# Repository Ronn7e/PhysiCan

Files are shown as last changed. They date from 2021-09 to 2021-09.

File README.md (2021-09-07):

# PhysiCan
PhysiCan es mi proyecto de Tesis para graduame en Ingeniería Electrónica. Se trata de una ortesis veterinaria robótica para la rehabilitación de rodilla en caninos. Se controla desde el celular mediante una aplicación y también monitorea (visualización de un Electromiagrama en la aplicación) la actividad muscular durante los ejercicios de rehabilitación.

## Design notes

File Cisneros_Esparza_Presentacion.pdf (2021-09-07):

### “DISEÑO E IMPLEMENTACIÓN DE UNA ORTESIS VETERINARIA DE UN GRADO DE LIBERTAD UTILIZADA EN LA FASE II DE LA REHABILITACIÓN DE RODILLA EN CANINOS DE LA FUNDACIÓN PAE”

Autores:
Cisneros Jumbo, Diego Sebastián Esparza Echanique, Ronnie Alexis

Director:
Ing. Erazo Sosa, Andres Sebastian

Fecha:
05/07/2019

## INGENIERÍA EN ELECTRÓNICA, AUTOMATIZACIÓN Y CONTROL

# CONTENIDO

▹ INTRODUCCIÓN
- Antecedentes
- Justificación e Importancia
- Alcance
- Objetivos
▹ FUNDAMENTOS TEÓRICOS
▹ READECUACIÓN DE LA ORTESIS VETERINARIA
- Parámetros de la ortesis veterinaria
- Cálculo del torque para mover la pierna del canino
- Selección del actuador
- Adaptación física de la ortesis
- Parámetros para realizar los ejercicios de rehabilitación
- Sistema de control

2

▹ CIRCUITO PARA
ELECTROMIOGRAFÍA EN CANINOS
- Parámetros de un
electromiograma (EMG)
- Diseño del circuito
- Análisis para el uso del EMG en caninos
▹ DISEÑO DE LA APLICACIÓN MÓVIL ▹ RESULTADOS
- Integración de la ortesis + EMG + App (Sistema PhysiCan)
- Funcionamiento
▹ CONCLUSIONES

1.

# INTRODUCCIÓN

### La fisioterapia veterinaria a través de los años…

3

4

# INTRODUCCIÓN

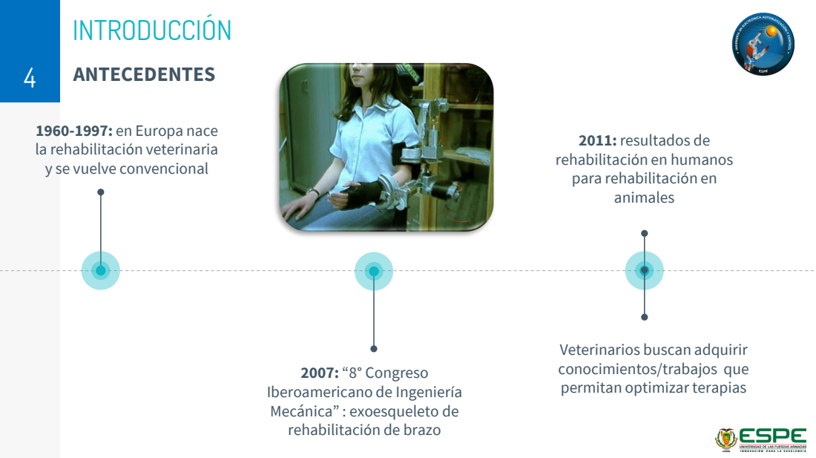
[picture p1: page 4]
ANTECEDENTES

1960-1997: en Europa nace
la rehabilitación veterinaria
y se vuelve convencional

2011: resultados de
rehabilitación en humanos
para rehabilitación en
animales

Veterinarios buscan adquirir
conocimientos/trabajos que
permitan optimizar terapias

2007: “8° Congreso
Iberoamericano de Ingeniería
Mecánica” : exoesqueleto de
rehabilitación de brazo

5

# INTRODUCCIÓN

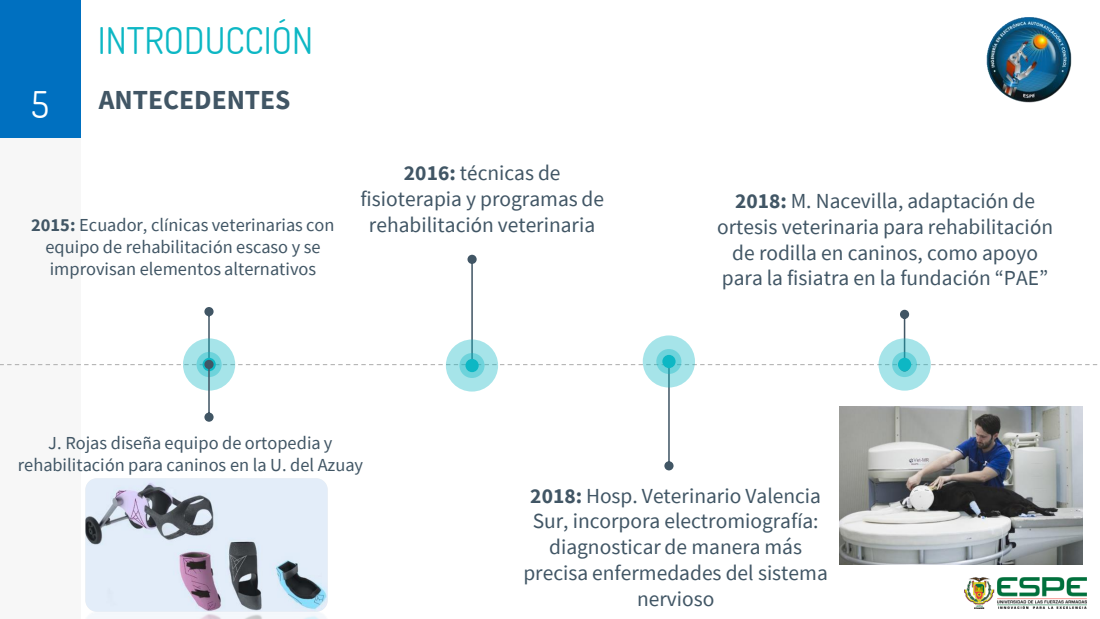
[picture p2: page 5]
ANTECEDENTES; nervioso

2016: técnicas de
fisioterapia y programas de
rehabilitación veterinaria

2018: M. Nacevilla, adaptación de
ortesis veterinaria para rehabilitación
de rodilla en caninos, como apoyo
para la fisiatra en la fundación “PAE”

2015: Ecuador, clínicas veterinarias con
equipo de rehabilitación escaso y se
improvisan elementos alternativos

J. Rojas diseña equipo de ortopedia y
rehabilitación para caninos en la U. del Azuay

2018: Hosp. Veterinario Valencia
Sur, incorpora electromiografía:
diagnosticar de manera más
precisa enfermedades del sistema

# INTRODUCCIÓN

JUSTIFICACIÓN E IMPORTANCIA
☐ En el país no ha existido avance en cuanto a ortopedia canina a nivel tecnológico.

☐ PAE, clínica que posee la Ortesis de Rehabilitación creada por Ing. Mireya Nacevilla con puntos a mejorar.

☐ 2013, REDVET: “La terapia física en medicina veterinaria es un tema nuevo que se debe integrar como parte de los tratamientos en las clínicas… con uso de nueva tecnología”.

6

# INTRODUCCIÓN

JUSTIFICACIÓN E IMPORTANCIA
☐ Para 2016 las mascotas han pasado de ser animales para cuidado y seguridad a considerarse como parte de la familia y solo en Quito están presentes en el 43% de los hogares. Teniendo un mercado nacional de 58 millones de dólares.

☐ Plan Nacional para el Buen Vivir (2017-2021): Objetivo 5, Política 5.3 : Promover la investigación, formación, capacidad y transferencia tecnológica, innovación y emprendimiento, en articulación con las necesidades sociales, para impulsar el cambio en la matriz productiva.

☐ Reglamento Nacional de Tenencia de Perros: Art 3: es obligación del propietario otorgar las condiciones de vida adecuadas y un hábitat dentro de un entorno saludable. (Secretaría General, Ministerio de Salud, 2009)

6

# INTRODUCCIÓN

ALCANCE

☐ Automatización de los ejercicios de rehabilitación, de manera que la fisiatra pueda atender otros pacientes a la par.
☐ Trabajar sobre el prototipo de M. Nacevilla: nuevo motor, sensado de actividad muscular (EMG), aumentar prestaciones aplicación móvil.
☐ Aumentar rangos de movimiento (limitado de 120° y 80° ), capacidad de carga del motor, control de velocidad, generación de historia clínica.

8

# INTRODUCCIÓN

8

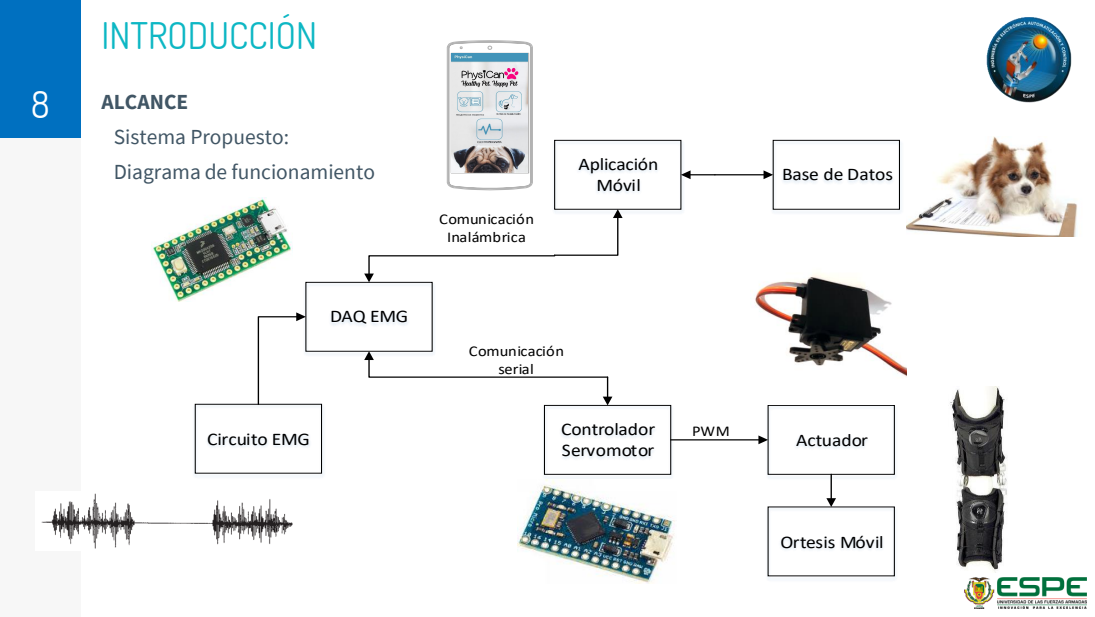
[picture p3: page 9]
Circuito EMG; Aplicación Móvil; Controlador; Servomotor; Actuador; Ortesis Móvil; DAQ EMG; Comunicación Inalámbrica; Comunicación serial; PWM

ALCANCE
Sistema Propuesto:
Diagrama de funcionamiento

Base de Datos

# INTRODUCCIÓN

OBJETIVO GENERAL

## ☐ Diseñar e implementar un prototipo portátil de ortesis de un grado de libertad utilizada en la rehabilitación de rodilla en caninos con

visualización EMG digital.

10

# INTRODUCCIÓN

OBJETIVOS ESPECÍFICOS
☐ Implementar un controlador y actuador adecuados

☐ Nueva interfaz gráfica

☐ Nuevo método de control

☐ Monitoreo EMG

☐ Manejo correcto del actuador

☐ Protocolo de transmisión de datos

11

2.

# FUNDAMENTOS TEÓRICOS

12

# FUNDAMENTOS TEÓRICOS

CINESITERAPIA PASIVA
“…Conjunto de técnicas de dos tipos, manuales o instrumentales que buscan el movimiento de segmentos corporales mediante un elemento que aplica una fuerza externa…” (Mejía & Saavedra, 2008).

ORTESIS VETERINARIA
“… Dispositivo ortopédico aplicado de forma externa en el cuerpo o extremidad…” (Rubio Fernández, 2011)

RANGOS DE MOVIMIENTO PASIVO (PROM)
“… Los rangos o gama de movimientos pasivos comprenden el grado de movilidad que se lograría en determinada articulación después de aplicar una fuerza externa…” (Ruiz & Amils, 2011)

12

# FUNDAMENTOS TEÓRICOS

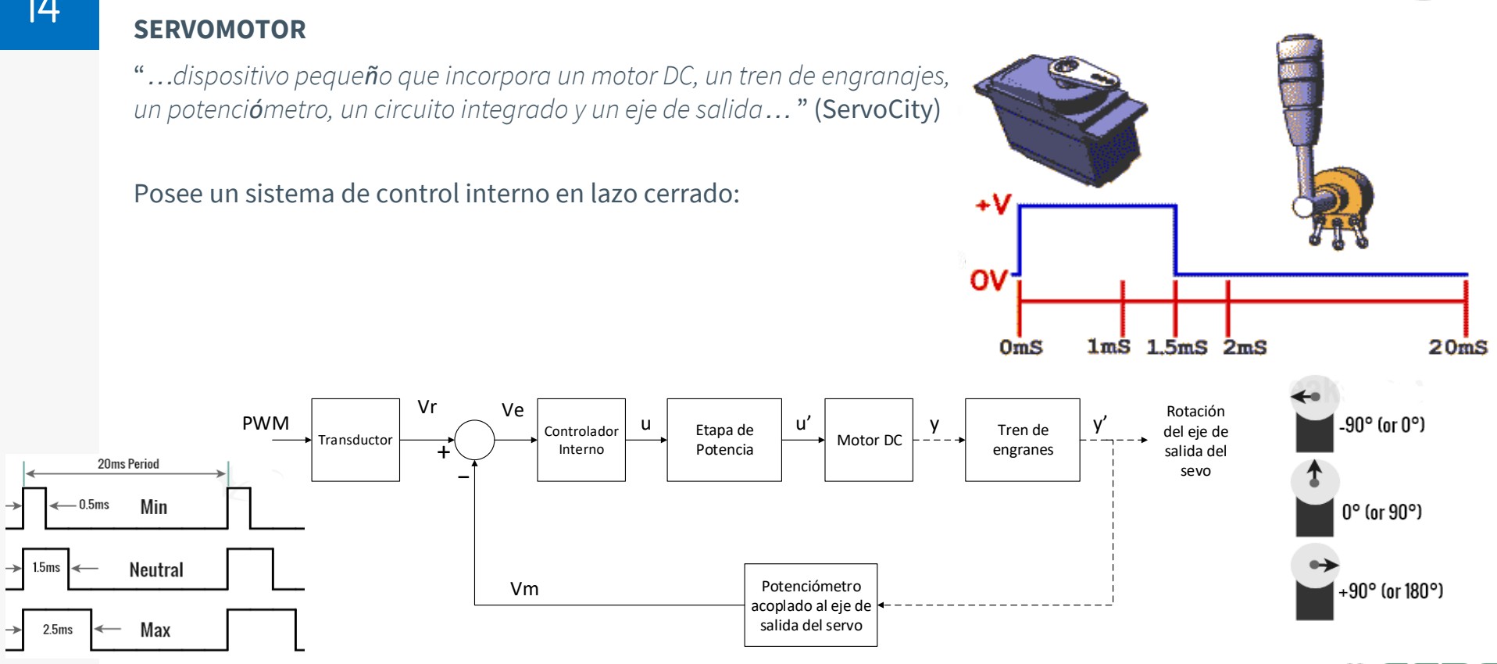
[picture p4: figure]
SERVOMOTOR; Transductor; Controlador; Interno; Etapa de Potencia; Potenciómetro acoplado al eje de salida del servo; Motor DC; Tren de; engranes; PWM; Rotación del eje de salida del sevo

“…dispositivo pequeño que incorpora un motor DC, un tren de engranajes, un potenciómetro, un circuito integrado y un eje de salida… ” (ServoCity)

14

Posee un sistema de control interno en lazo cerrado:

ELECTROMIOGRAFÍA
“… Es una prueba para estudiar como funcionan muchos de los nervios que transmiten la sensibilidad y la fuerza, así como los músculos…” (Agencia Valenciana de Salud)

15

# FUNDAMENTOS TEÓRICOS

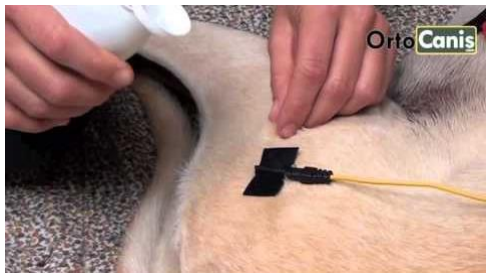
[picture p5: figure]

REGISTRO DE LA ACTIVIDAD ELECTRICA DURANTE LA CONTRACCIÓN MUSCULAR

# FUNDAMENTOS TEÓRICOS

16

☐ Estudios Clínicos, Asociación Argentina de Neurología Veterinaria

INSERCIÓN DE ELECTRODO DE AGUJA

MUSCULO ESTIMULADO/MUSCULO EN REPOSO MOVIMIENTO VOLUNTARIO

3.

# READECUACIÓN DE LA ORTESIS VETERINARIA

17

La tecnología aplicada a la rehabilitación de caninos.

# READECUACIÓN DE LA ORTESIS VETERINARIA

PARÁMETROS DE LA ORTESIS VETERINARIA

☐ Modelo Caerus CCL Stifle (Knee) Brace (XS):

18

Tamaño | Longitud de la tibia [cm] | Masa [kg]
X-Small | 8.89 – 13.97 | 4.54 – 11.34 kg
- Diseño modular
- Bisagras para ajuste/bloqueo del movimiento de la rodilla
- Sistema giratorio de fijación

# READECUACIÓN DE LA

# ORTESIS VETERINARIA

CÁLCULO DEL TORQUE PARA MOVER LA PIERNA DEL CANINO ☐ Sistema de palancas del miembro posterior:
- Tercer tipo o interpotente:
Fp: fuerza de potencia o motriz
Fr: Fuerza de carga o resistente
Bp: brazo potente (distancia entre la potencia y el punto de apoyo)
Br : Brazo resistente (distancia entre el apoyo y la carga o resistencia)
F: rodilla o punto de apoyo
- En el canino el brazo potente (Bp) corresponde al músculo poplíteo, responsable de la flexión de la rodilla.

19

# READECUACIÓN DE LA ORTESIS VETERINARIA

CÁLCULO DEL TORQUE PARA MOVER LA PIERNA DEL CANINO ☐ Distribución de masa corporal del canino.

- Se consideró el caso más extremo
- Masa total de 11.34 kg y una longitud de la tibia de 13.97 cm.

20

Total | Muslo | Pierna | Pie
11.34 kg | 1.0206 kg | 0.417312 kg | 0.291438 kg

# READECUACIÓN DE LA 21 ORTESIS VETERINARIA

CÁLCULO DEL TORQUE PARA MOVER LA PIERNA DEL CANINO

Mr = Mp

Mr = Fr1 × Br1 + Fr2 × Br2

Fr1 = 0.4173 + 0.150 | kg | × 9.8

m
s
2 | = 5.55954 [N]
Fr2 = 0.2914 | kg | × 9.8

m
s
2 | = 2.8557 | N
Mr = 5.55954 | N | × 0.06985 | m | + 2.8557 | N | × 0.1397 | m

Mr = Mp = 0.7872[N. m]

### 13.97 cm

# READECUACIÓN DE LA ORTESIS VETERINARIA

SELECCIÓN DEL ACTUADOR

22

Características | Opción 1 | Opción 2 | Opción 3
Marca | Pololu | Pololu | Hitec
Modelo | 20Dx44L (producto 3491) | 25Dx64L (producto 3217 ) | HS-755 HB
Torque | 0.77 Nm | 1.16 Nm | 1.07 Nm
Existencia en el mercado nacional | No | Si | Si
Peso | 46 gr | 101 gr | 110 gr
Voltaje de operación | 12 V | 12 V | 4.8 V
Corriente máxima | 1600 mA | 5600 mA | 1500 mA
Sensor de posición inetegrado | No (opción para acople) | Si | Si (No accesible)
Posición del eje | Horizontal | Horizontal | Vertical
Precio | $22,95 (USA) | $39,99 | $40
Rango de movimiento angular | 0-360° | 0-360° | 0-180°

# READECUACIÓN DE LA ORTESIS VETERINARIA

ADAPTACIÓN FÍSICA DE LA ORTESIS

23

Modo de

# READECUACIÓN DE LA ORTESIS VETERINARIA

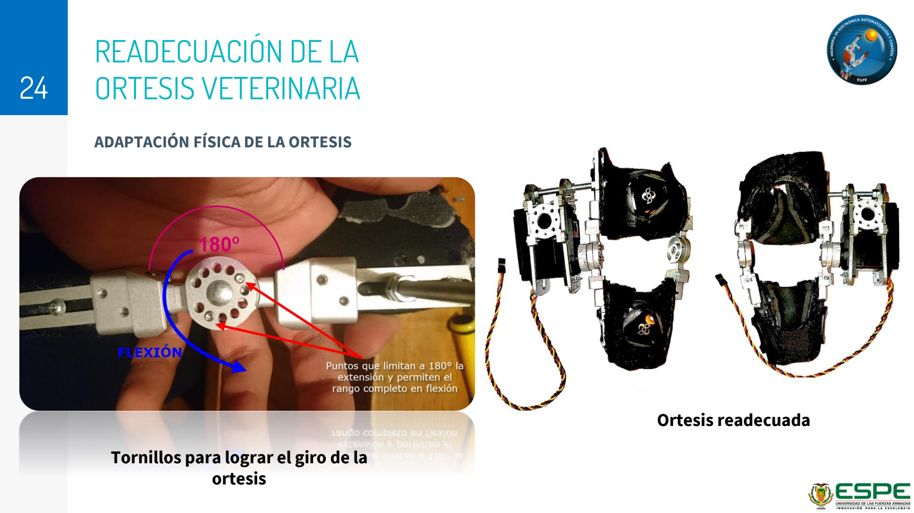
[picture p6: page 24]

ADAPTACIÓN FÍSICA DE LA ORTESIS

24

Tornillos para lograr el giro de la ortesis

Ortesis readecuada

# READECUACIÓN DE LA ORTESIS VETERINARIA

PARÁMETROS PARA REALIZAR LOS EJERCICIOS DE REHABILITACIÓN
25

# READECUACIÓN DE LA ORTESIS VETERINARIA

SISTEMA DE CONTROL

26

Parámetros de
configuración
para la
rehabilitación

Rotación
del eje de
Rotación
de la
Ortesis
Móvil

Diagrama de bloques de un sistema en lazo abierto (Kuo)

Controlador; Externo; Servomotor; Bisagra de la; Ortesis Móvil; PWM; salida del sevo

Diagrama de bloques de la ortesis readecuada

# READECUACIÓN DE LA ORTESIS VETERINARIA

SISTEMA DE CONTROL

27

Microprocesador | ATmega32U4
Alimentación / reloj | 5V
Reloj | 16 MHz
IDE de Programación | Compatible con Arduino IDE desde v1.0.1
Programación | On-Board micro-USB
Digital I/Os | 12 (5 se pueden utilizar como PWM)
Comunicación serial | Micro USB y mediante pines RX y TX
Tamaño | 1.3 x 0.7" (33.02 x 17.78 mm ) | Tarjeta de desarrollo SparkFun
Pro Micro

4.

# CIRCUITO PARA ELECTROMIOGRAFÍA EN CANINOS

28

Midiendo la atividad muscular en la rehabilitación.

# CIRCUITO PARA ELECTROMIOGRAFÍA EN CANINOS

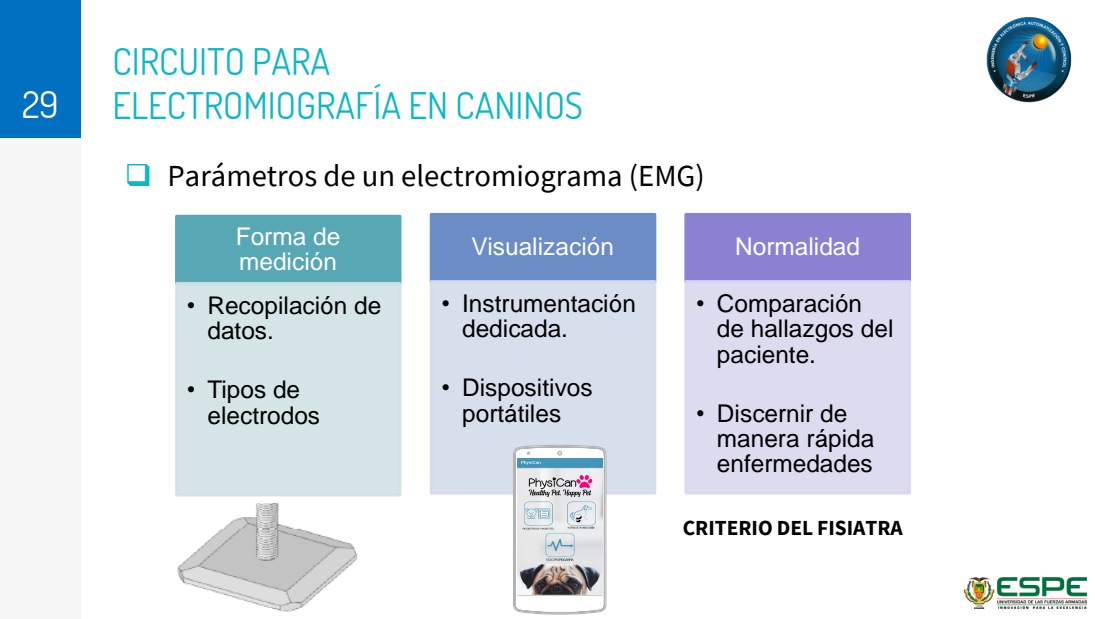
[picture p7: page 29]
Forma de medición; • Recopilación de datos.; • Tipos de electrodos; Visualización; • Instrumentación dedicada.; • Dispositivos portátiles; Normalidad; • Discernir de manera rápida enfermedades

☐ Parámetros de un electromiograma (EMG)

• Comparación
de hallazgos del
paciente.

CRITERIO DEL FISIATRA

# CIRCUITO PARA ELECTROMIOGRAFÍA EN CANINOS

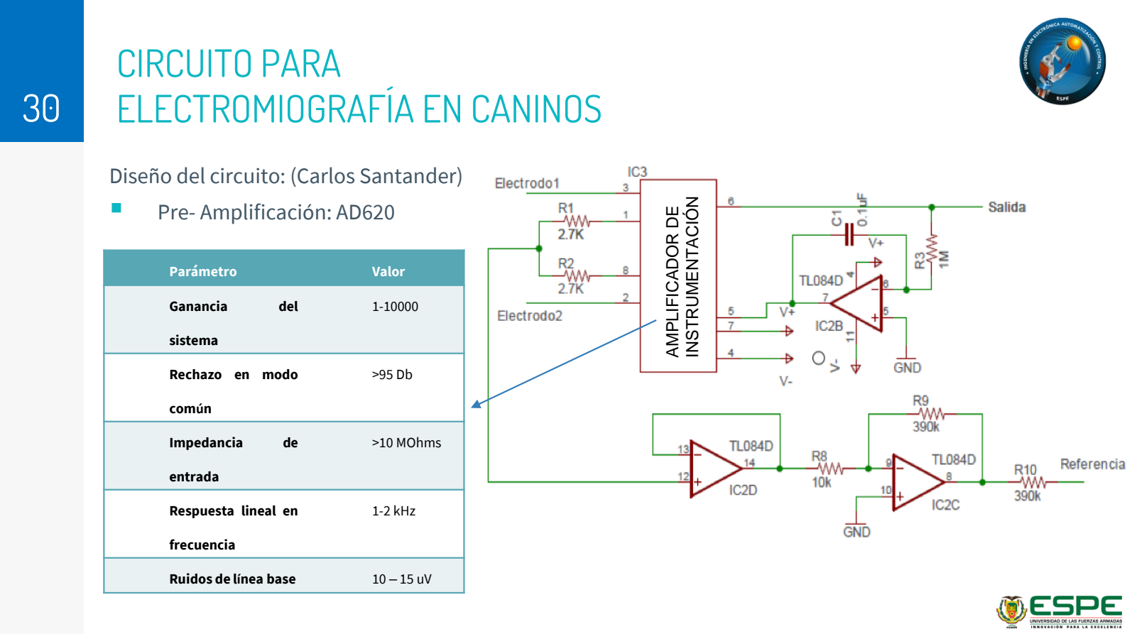
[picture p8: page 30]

Diseño del circuito: (Carlos Santander)
- Pre- Amplificación: AD620

30

Parámetro | Valor
Ganancia del sistema | 1-10000
Rechazo en modo común | >95 Db
Impedancia de entrada | >10 MOhms
Respuesta lineal en frecuencia | 1-2 kHz
Ruidos de línea base | 10 – 15 uV

AMPLIFICADOR DE

INSTRUMENTACIÓN

# CIRCUITO PARA

31 | ELECTROMIOGRAFÍA EN CANINOS | Sistema de

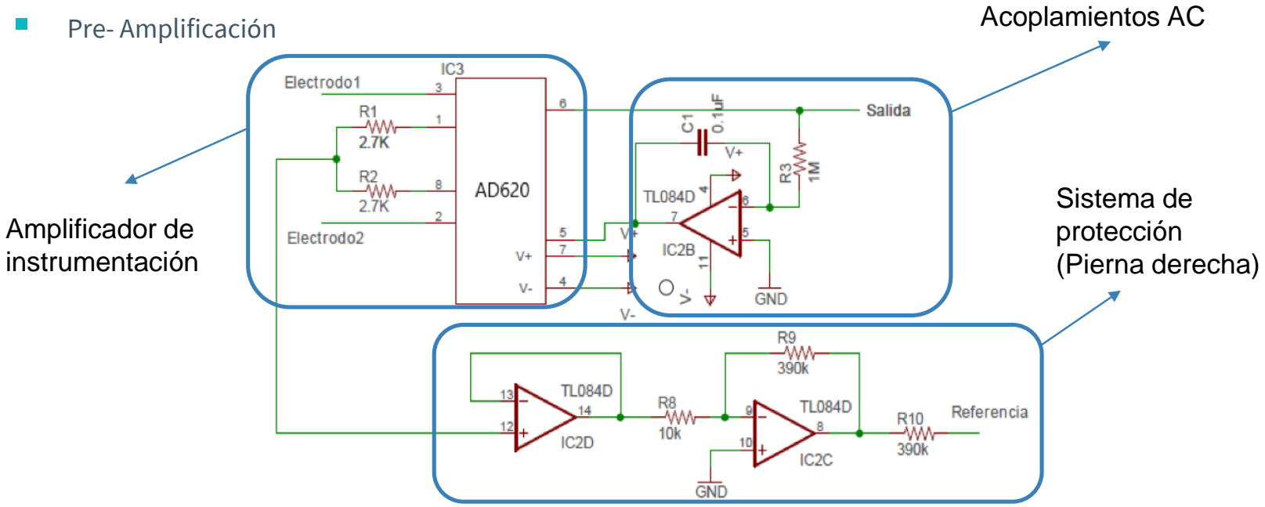
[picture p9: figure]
Acoplamientos AC; Sistema de protección (Pierna derecha); Amplificador de instrumentación; ▪ Pre- Amplificación

# CIRCUITO PARA ELECTROMIOGRAFÍA EN CANINOS

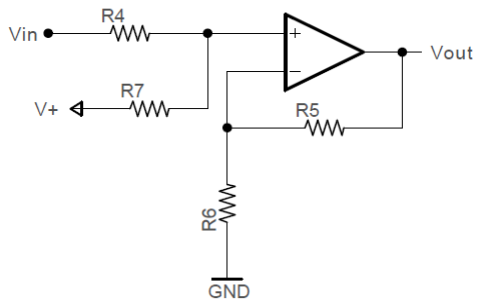
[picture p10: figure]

- Amplificación

32

Valores apropiados - A/D

Valores comerciales del
“uC” [-3;3 mV] o [-3;3 V]

Incremento
de la
amplitud

# CIRCUITO PARA ELECTROMIOGRAFÍA EN CANINOS

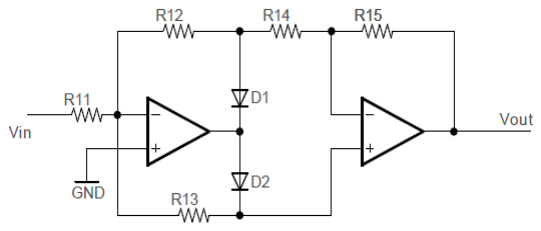
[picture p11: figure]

- Rectificación

33

Trabajo con:
Teensy 3.2

Valores de [0;3]V o
de [0;5]V

Requerimientos

# CIRCUITO PARA ELECTROMIOGRAFÍA EN CANINOS

- Procesamiento de la señal: Tarjeta Teensy 3.2

34

Dimensiones | 18mm x 37 mm x 4mm
Arquitectura y frecuencia de trabajo | 32-bit ARM Cortex-M4 de 72MHz
Capacidad de memoria | Memoria Flash 256K, RAM 64K, EEPROM 2K
Entradas y salidas | 34 entradas/salidas digitales, 12 salidas PWM
Temporizadores | 7 temporizadores de intervalo/retardo
Manejo de interrupciones | Todos los pines tienen capacidad de interrupción

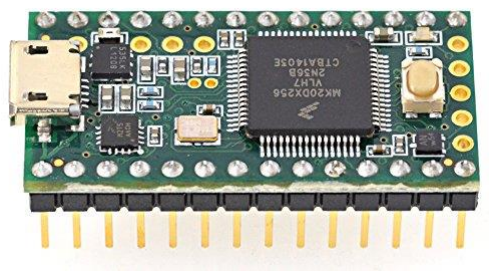
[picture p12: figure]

Frecuencia típica de un EMG: 50Hz – 500Hz

Máxima potencia de la señal: 70Hz y 300Hz

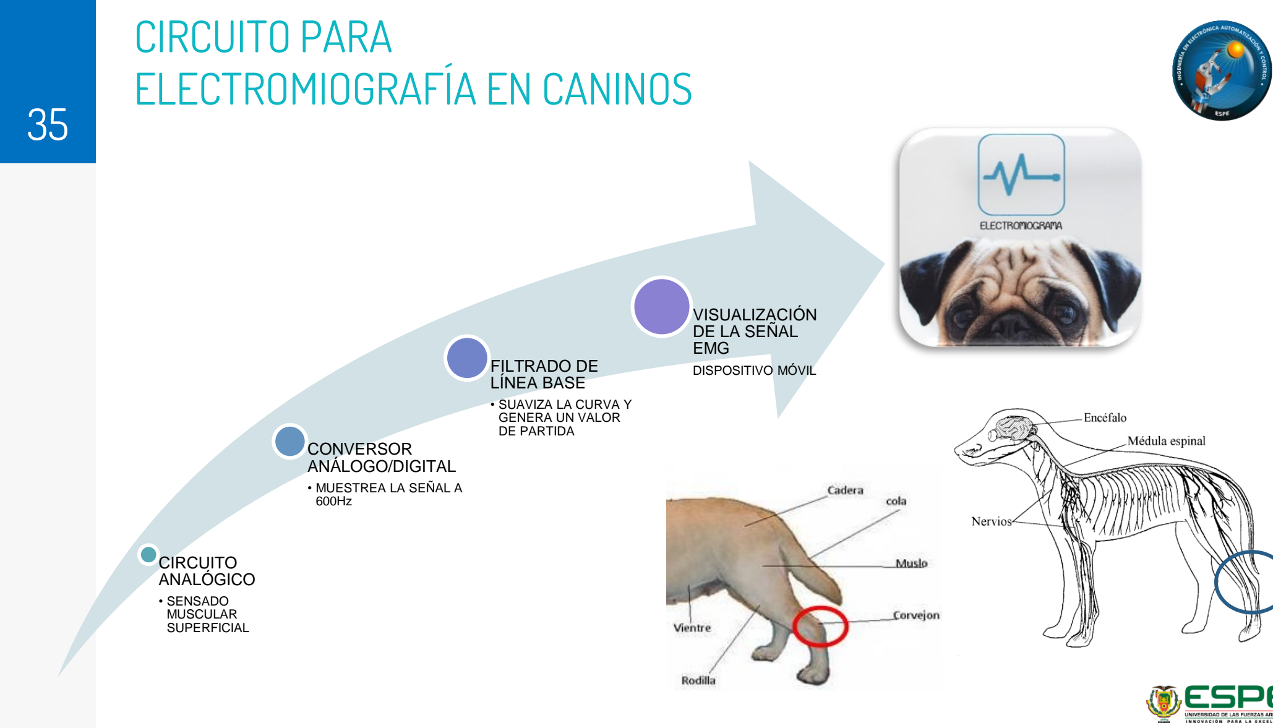
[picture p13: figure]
CIRCUITO PARA ELECTROMIOGRAFÍA EN CANINOS; CIRCUITO ANALÓGICO; • SENSADO MUSCULAR SUPERFICIAL; CONVERSOR ANÁLOGO/DIGITAL; • MUESTREA LA SEÑAL A 600Hz; FILTRADO DE LÍNEA BASE; • SUAVIZA LA CURVA Y GENERA UN VALOR DE PARTIDA; VISUALIZACIÓN DE LA SEÑAL EMG; DISPOSITIVO MÓVIL

5.

# DISEÑO DE LA APLICACIÓN MÓVIL

36

El manejo de la rehabilitación a través del teléfono.

37

# DISEÑO DE LA APLICACIÓN

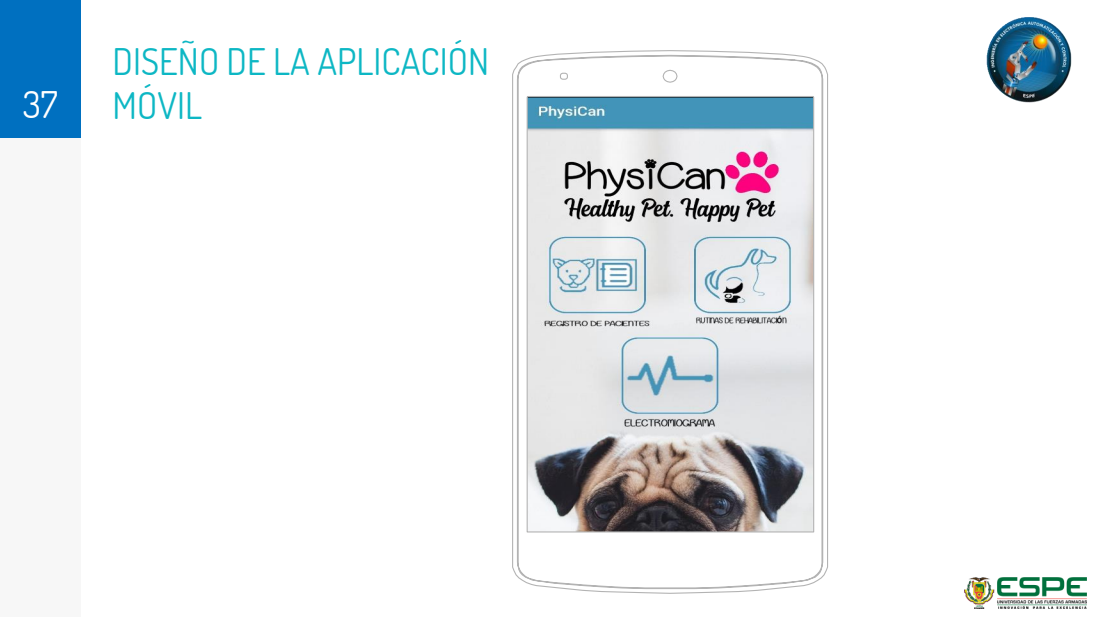
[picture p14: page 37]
MÓVIL

# DISEÑO DE LA APLICACIÓN MÓVIL

☐ Primera versión

38

# DISEÑO DE LA APLICACIÓN MÓVIL

☐ Segunda versión

39

# DISEÑO DE LA APLICACIÓN MÓVIL

40 ☐ Segunda versión

# DISEÑO DE LA APLICACIÓN MÓVIL

☐ Formato de Historia clínica automatizada 41

6.

# RESULTADOS

42

### ¿Se pudieron unir los sistemas?

# RESULTADOS

43 ☐ Integración de la ortesis + EMG + App = Sistema PhysiCan

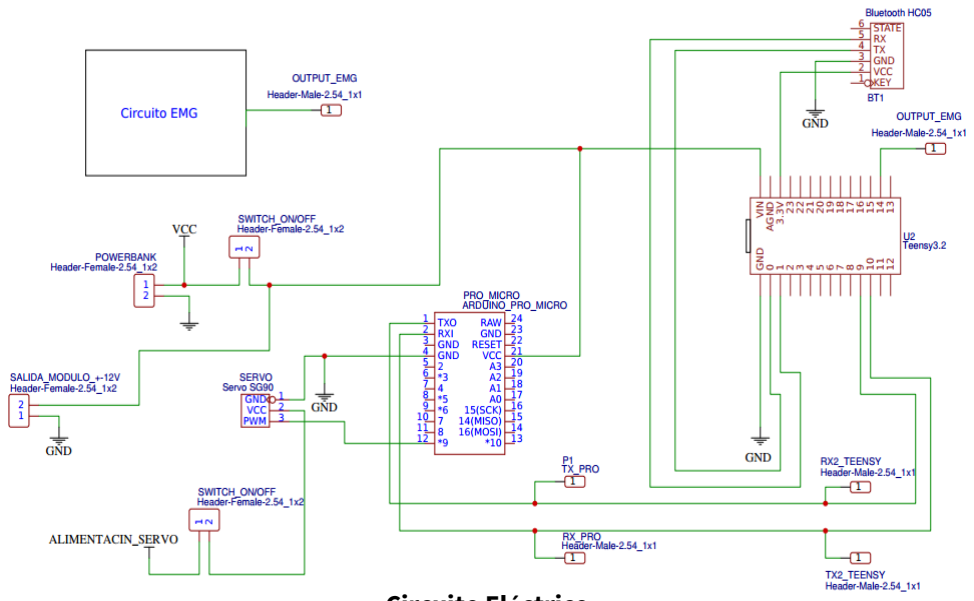
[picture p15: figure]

Circuito Eléctrico

# RESULTADOS

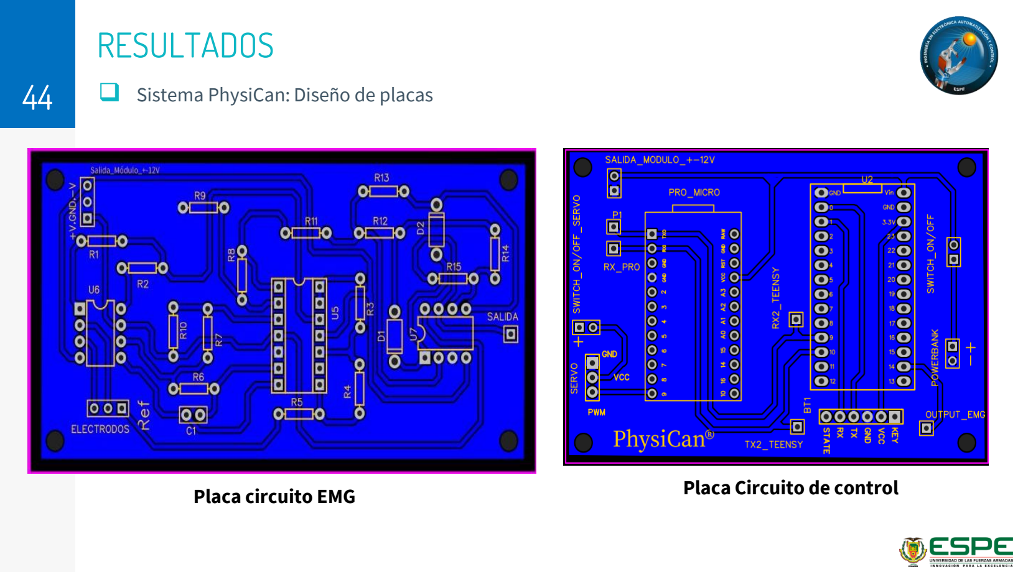
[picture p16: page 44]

44 | ☐ Sistema PhysiCan: Diseño de placas
Placa circuito EMG | Placa Circuito de control

# RESULTADOS

### 45 ☐ Sistema PhysiCan: Carcasa e implementación

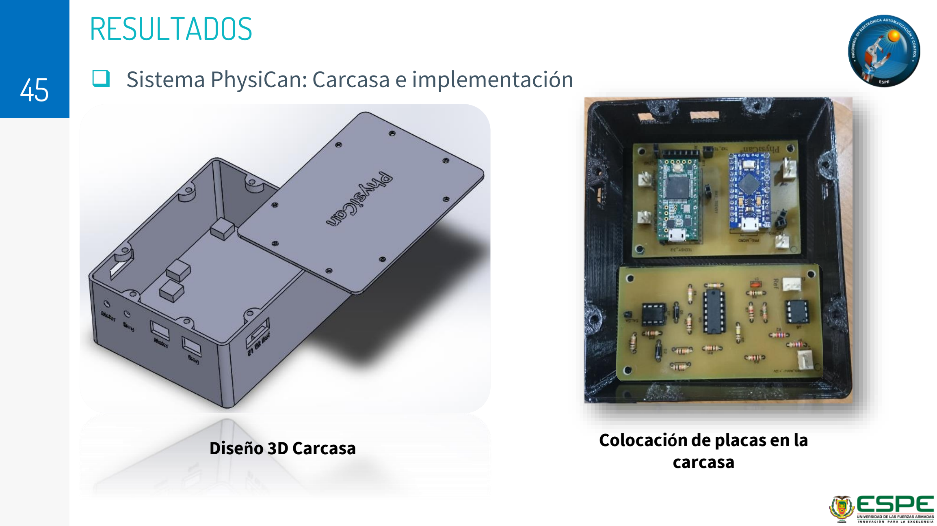
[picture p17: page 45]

Diseño 3D Carcasa | Colocación de placas en la carcasa

# RESULTADOS

46 ☐ Sistema PhysiCan: Carcasa e implementación

Fijación de placas, módulos y conectores

# RESULTADOS

47

# RESULTADOS

48 | ☐ Pruebas de la Ortesis readecuada: Capacidad de movimiento
| ▹ Primeras pruebas de carácter netamente funcional guiadas de la fisiatra de PAE. ▹ Se realizaron con un canino de la fundación PAE de aproximadamente 6 kg de peso, de raza mestiza; como dato adicional el paciente se encontraba decaído y se encontraba en recuperación; y no presentaba problemas en la rodilla.
Número de prueba | Ángulo de flexión [°] | Tiempo de espera en flexión [s] | Ángulo de extensión [°] | Tiempo de espera en extensión [s] | Número de repeticiones | Velocidad (sin carga) [s/60°]
Primera | 100 | 3 | 170 | 3 | 3 | Baja(2.38 )
Segunda | 100 | 3 | 150 | 3 | 3 | Media(1.48)
Tercera | 100 | 3 | 150 | 3 | 3 | Alta (0.99)

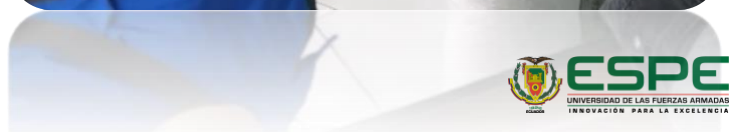
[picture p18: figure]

# RESULTADOS

### 49 ☐ Pruebas de la Ortesis readecuada

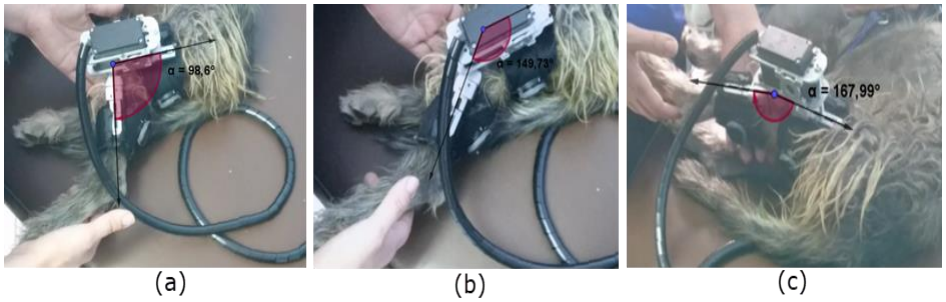
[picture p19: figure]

Ángulos logrados en las pruebas a) flexión 100° (valor logrado 98.6°), b) extensión 150° (valor logrado 149.73°) y c) extensión 170° (valor logrado 167.99°).

# RESULTADOS

50 | ☐ Pruebas de la Ortesis readecuada: Control de posición
| Se realizaron con otro canino de aproximadamente 7 kg de peso, de raza mestiza; como dato adicional el paciente no presentaba problemas en la rodilla.
Número de prueba | Ángulo de flexión [°] | Tiempo de espera en flexión [s] | Ángulo de extensión [°] | Tiempo de espera en extensión [s] | Número de repeticiones | Velocidad (sin carga) [s/60°]
Primera | 110 | 3 | 160 | 3 | 4 | Baja(2.38 )
Segunda | 110 | 3 | 160 | 3 | 4 | Media(1.48)
Tercera | 110 | 3 | 160 | 3 | 4 | Alta (0.99)

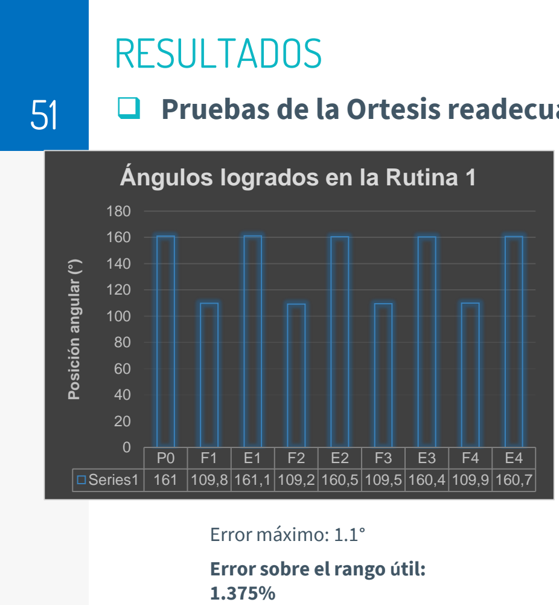
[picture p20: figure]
RESULTADOS; Error máximo: 1.1°; Error sobre el rango útil: 1.375%; Series1; Posición angular (°); Ángulos logrados en la Rutina 1

### 51 ☐ Pruebas de la Ortesis readecuada: Control de posición

Series1; Posición angular(°); Ángulos logrados en la Rutina 2

Error máximo: 1.9°
Error sobre el rango útil: 2.375%

# RESULTADOS

### 52 ☐ Pruebas de la Ortesis readecuada: Control de posición

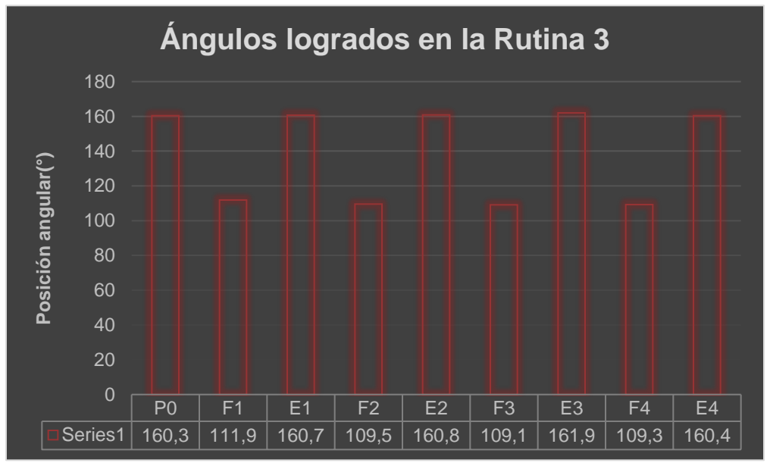
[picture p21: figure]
Series1; Posición angular(°); Ángulos logrados en la Rutina 3

Error máximo: 1.95°
Error sobre el rango útil: 2.44%

# RESULTADOS

### 53 ☐ Sistema de sensado Electromiográfico (Realizado a un integrante del grupo)

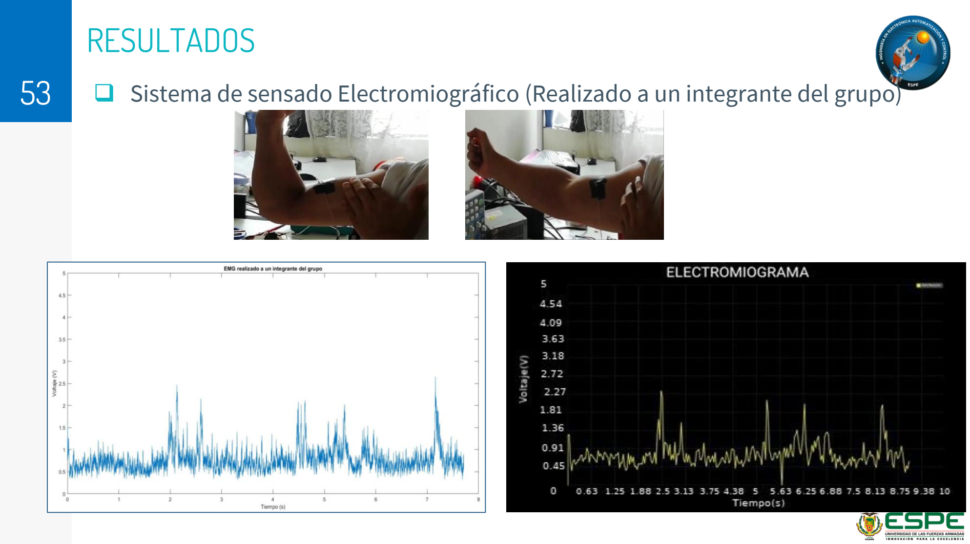
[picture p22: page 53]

# RESULTADOS

### ☐ Sistema de sensado Electromiográfico (Realizado a un paciente canino)

54

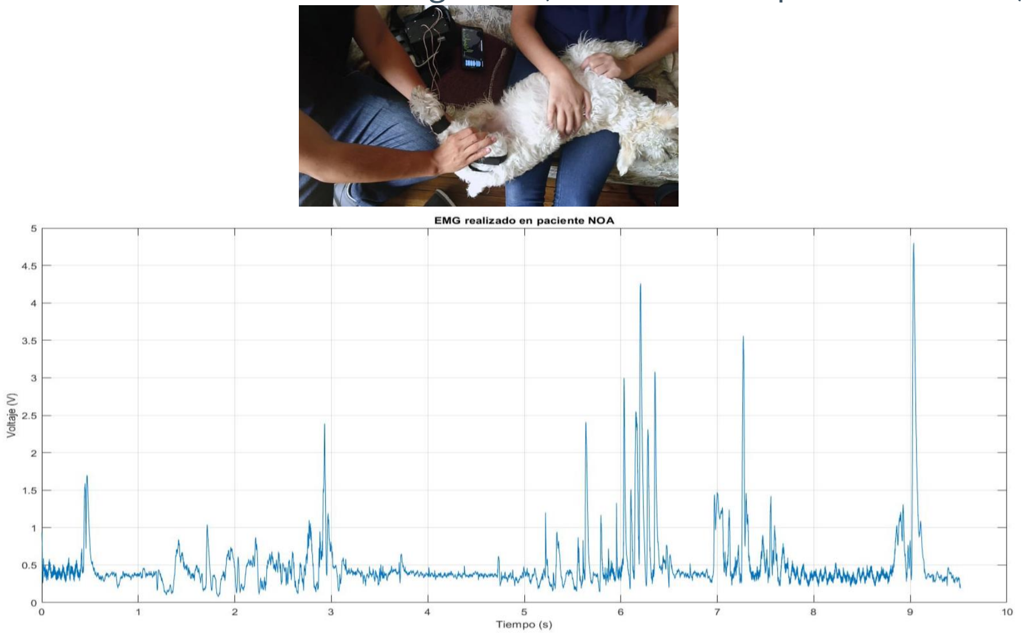
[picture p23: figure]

# RESULTADOS

### ☐ Ortesis + EMG: Video

55

# RESULTADOS

☐ CONDICIONES DE APROBACIÓN PARA UNA ORTESIS VETERINARÍA (Tarrago,2018)

56

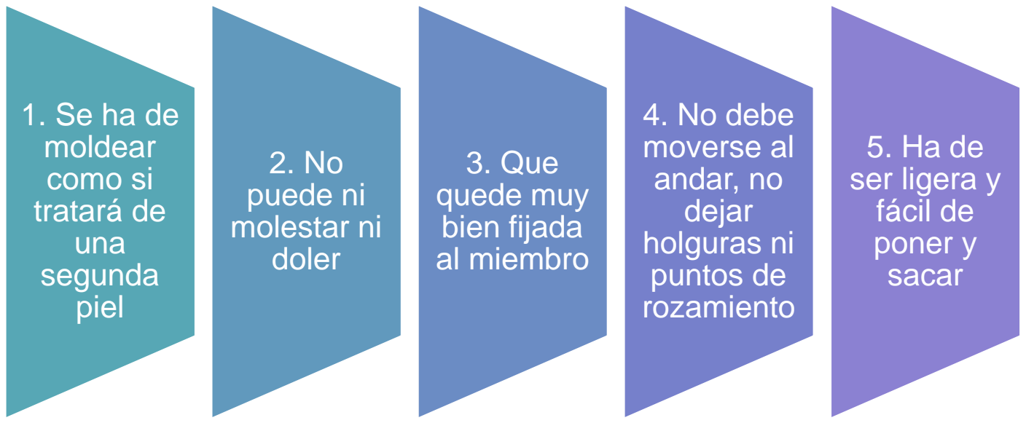
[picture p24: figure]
1. Se ha de moldear como si tratará de una segunda piel; 2. No puede ni molestar ni doler; 3. Que quede muy bien fijada al miembro; 4. No debe moverse al andar, no dejar holguras ni puntos de rozamiento; 5. Ha de ser ligera y fácil de poner y sacar

# RESULTADOS

☐ CONDICIONES DE APROBACIÓN PARA UNA ORTESIS VETERINARÍA(ENCUESTA)

57 | USTED CONSIDERA QUE:
1. ¿La ortesis veterinaria realizada se asemeja a una segunda piel para el paciente?
12. La relación obtenida a lo largo del estudio: "un disparo brusco en la señal EMG, representa dolor o molestia al momento de realizar la extensión o flexión en la extremidad" es correcta?
13. La señal EMG se mantenga a un nivel minimo al momento de realizar movimientos pasivos
8. Combinaría su técnica manual de fisioterapia con ejercicios que puede reemplazar la ortesis vetarinaria? *
9. Los movimientos de flexión y extensión corresponden a una cinesiterapia pasiva
10. El informe generado automaticamente por la aplicación movil le ayudaría a llevar un mejor control de cada paciente?
11. ¿Atendería un segundo paciente, mientras la ortesis veterinaria trabaja sobre el primero?
4. ¿Identificó algun punto de rozamiento en el uso de la ortesis con el paciente?
5. ¿Considera que la ortesis puede llegar a molestar en algun momento al animal?
6. ¿La señal EMG (Electromiograma) corresponde a una señal electromiográfica conocida por usted anteriormente?
7. ¿El EMG(Electromiograma) lo tomaría como apoyo para evaluar la recuperación del paciente?
2. ¿La ortesis realizada, podría ayudar a zonas de rotura por exceso de carga?
3. ¿La ortesis veterinaria molesta o queda mal fijada al miembro a tratar?

Por favor, conteste las siguiente encuesta con números del 1 al 5, donde 1 es "EN DESACUERDO" y 5 corresponde a un criterio "COMPLETAMENTE DE ACUERDO"

# RESULTADOS

☐ TABULACIÓN DE DATOS

58

USTED CONSIDERA QUE: | CALIFICACIÓN VETERIANARIO 1 | CALIFICACIÓN VETERINARIO 2 | CALIFICACIÓN VETERINARIO 3 | PROMEDIO DE CALIFICACIÓN
1. ¿La ortesis veterinaria realizada se asemeja a una segunda piel para el paciente? | 3 | 1 | 4 | 3
2. ¿La ortesis realizada, podría ayudar a zonas de rotura por exceso de carga? | 4 | 2 | 4 | 3
3. ¿La ortesis veterinaria molesta o queda mal fijada al miembro a tratar? | 3 | 2 | 5 | 3
4. ¿Identificó algun punto de rozamiento en el uso de la ortesis con el paciente? | 4 | 4 | 4 | 4
5. ¿Considera que la ortesis puede llegar a molestar en algun momento al animal? | 5 | 5 | 4 | 5
6. ¿La señal EMG (Electromiograma) corresponde a una señal electromiográfica conocida por usted anteriormente? | 4 | 5 | 5 | 5
7. ¿El EMG(Electromiograma) lo tomaría como apoyo para evaluar la recuperación del paciente? | 3 | 5 | 4 | 4
8. Combinaría su técnica manual de fisioterapia con ejercicios que puede reemplazar la ortesis vetarinaria? * | 4 | 2 | 5 | 4
9. Los movimientos de flexión y extensión corresponden a una cinesiterapia pasiva | 4 | 5 | 4 | 4
10. El informe generado automaticamente por la aplicación movil le ayudaría a llevar un mejor control de cada paciente? | 5 | 5 | 4 | 5
11. ¿Atendería un segundo paciente, mientras la ortesis veterinaria trabaja sobre el primero? | 4 | 4 | 5 | 4
12. La relación obtenida a lo largo del estudio: "un disparo brusco en la señal EMG, representa dolor o molestia al momento de realizar la extensión o flexión en la extremidad" es correcta? | 3 | 3 | 5 | 4
13. La señal EMG se mantenga a un nivel minimo al momento de realizar movimientos pasivos | 3 | 3 | 5 | 4

# RESULTADOS

☐ ANÁLISIS

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
1 | 2 | 3 | 4 | 5 | 6 | 7 | 8 | 9 | 10 11 12 13

ANALISIS DE DATOS

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
5 | 4 | 3 | 2 | 1

ANALISIS DE SUBJETIVIDAD

VETERINARIO 1 | VETERINARIO 2 | VETERINARIO 3
PREGUNTAS

PROMEDIO

CALIFICACIÓN

CANTIDAD

7.

# CONCLUSIONES

60

### ¿Qué se logró?

61 CONCLUSIONES ▪ Dispositivo Modular ▪ Desplazamiento angular ▪ Actividad Eléctrica Muscular

- Aumento de prestaciones
- Rangos de movimiento
- Validación de ingreso de datos reales
- EMG como medida indirecta de dolor
- Nueva limitación por
seguridad
- No existe interferencia entre los 2 sistemas
- Dimensionamiento de
torque
- Supera la primera versión
- Aumento de rango en 100%
- Control en posición de lazo abierto
- Primera versión: 4° - 10% error
- Segunda versión: 2° - 2,5% error
- Circuito EMG no invasivo
- Innovación como sensado
EMG portátil

62

# Gracias!

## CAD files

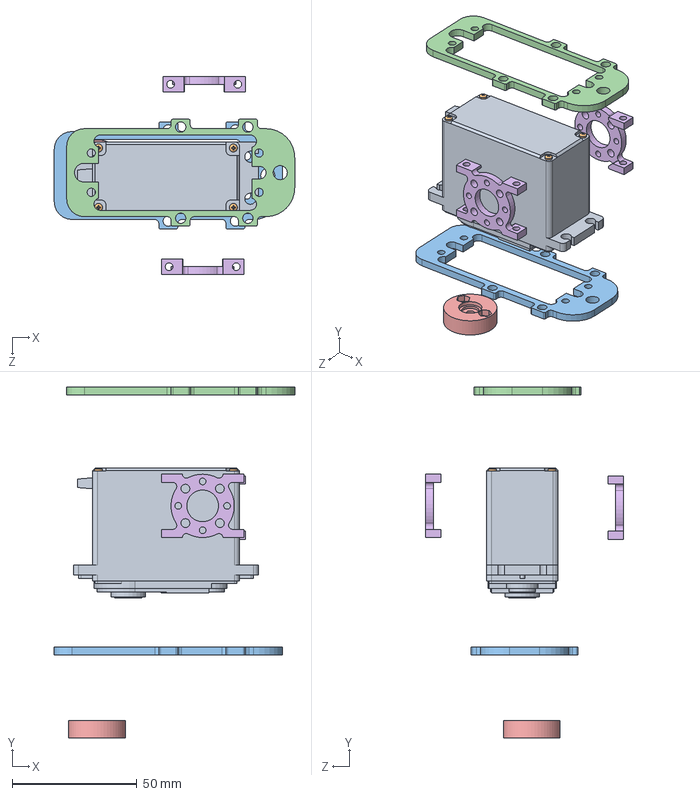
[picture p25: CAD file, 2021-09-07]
ESTRUCTURA DE ACOPLE/Ensamblaje3.SLDASM
96.5 x 140.8 x 79.5 mm
Carcasa Servo Hitec HB-755HB
pan cross head screw_as_AS-NZS 1427 PC- M1.6 x 5-N x 4
Pieza_base_inferior_imprimir_3d
Pieza_base_superior_imprimir_3d
Pieza_eje_bien_imprimir_3d_v4
Pieza_lateral x 2

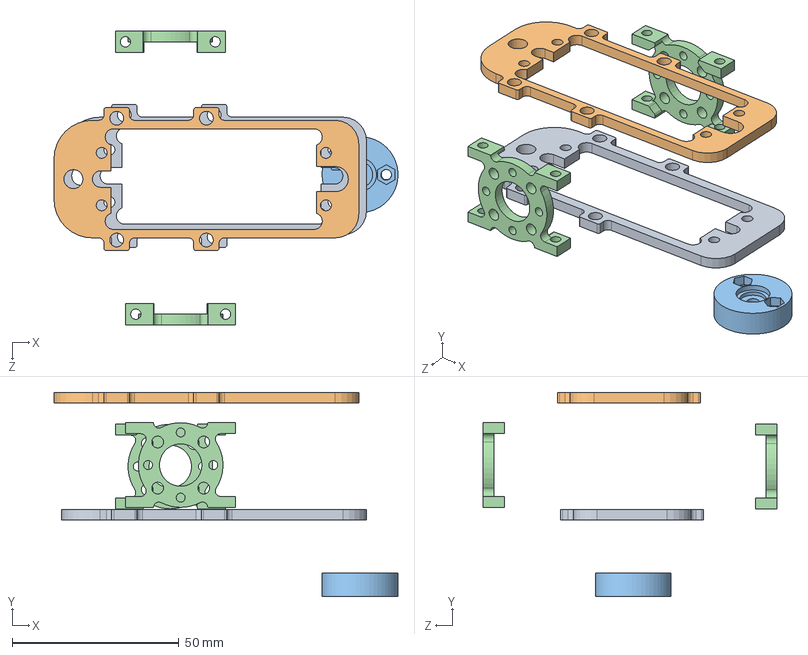
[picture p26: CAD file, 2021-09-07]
ESTRUCTURA DE ACOPLE/Ensamblaje1.SLDASM
103.3 x 61.3 x 88.1 mm
Pieza_base_inferior_imprimir_3d
Pieza_base_superior_imprimir_3d
Pieza_eje_bien_imprimir_3d_v4
Pieza_lateral x 2

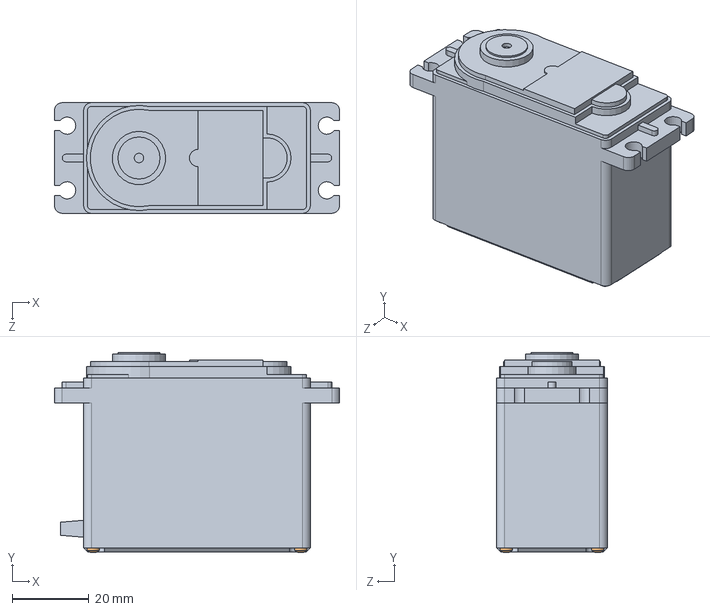
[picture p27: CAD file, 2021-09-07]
ESTRUCTURA DE ACOPLE/Servo_motor1.SLDASM
74.3 x 52.2 x 28.9 mm
Carcasa Servo Hitec HB-755HB
pan cross head screw_as_AS-NZS 1427 PC- M1.6 x 5-N x 4

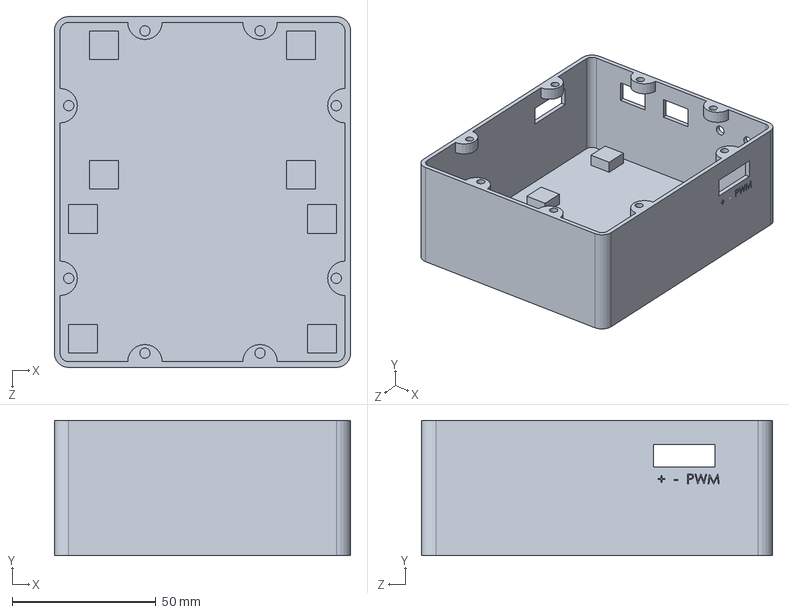
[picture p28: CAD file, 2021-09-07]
CAJA/caja_v5.SLDPRT
103.0 x 47.0 x 122.0 mm

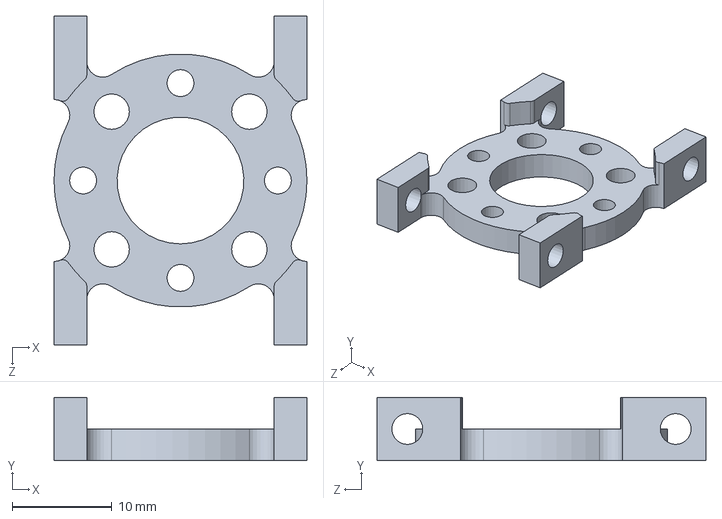
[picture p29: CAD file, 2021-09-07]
ESTRUCTURA DE ACOPLE/Pieza_lateral.SLDPRT
25.4 x 6.35 x 33.0 mm

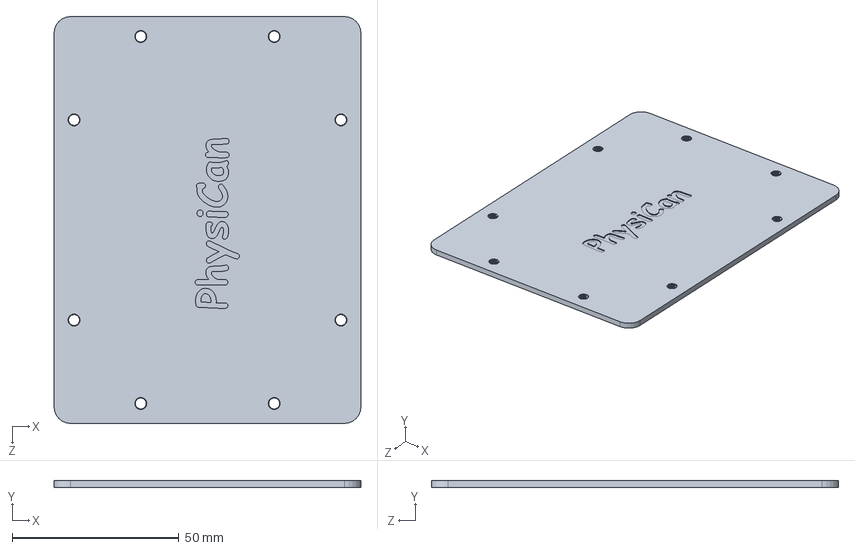
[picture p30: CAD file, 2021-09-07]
CAJA/tapa_caja_v3.SLDPRT
92.0 x 2.00 x 122.0 mm

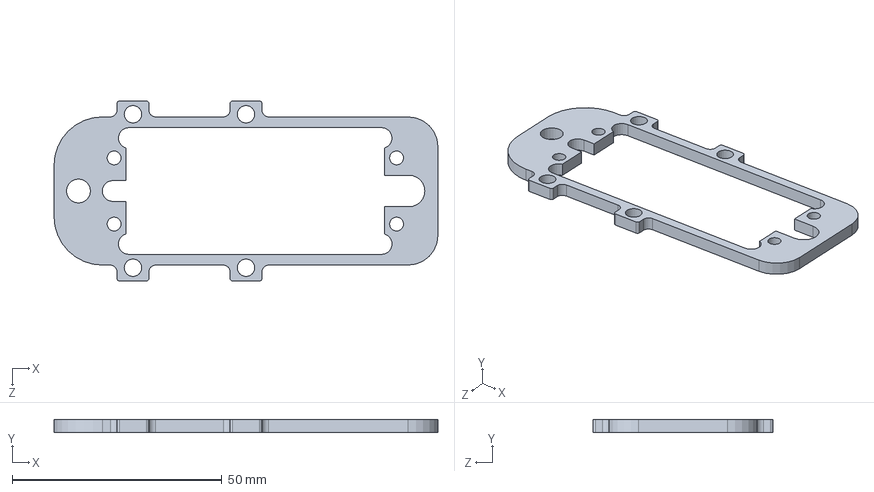
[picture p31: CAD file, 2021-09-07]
ESTRUCTURA DE ACOPLE/Pieza_base_superior_imprimir_3d.SLDPRT
91.5 x 3.17 x 42.9 mm

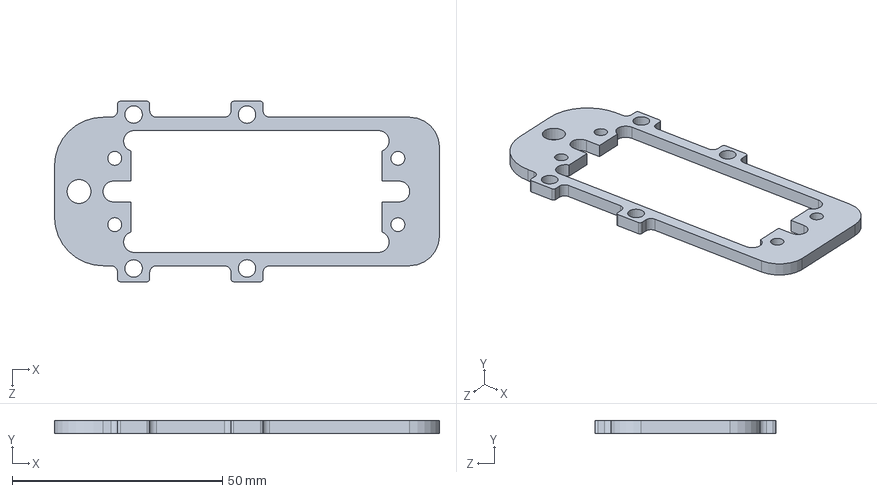
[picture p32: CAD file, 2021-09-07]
ESTRUCTURA DE ACOPLE/Pieza_base_inferior_imprimir_3d.SLDPRT
91.5 x 3.17 x 42.9 mm

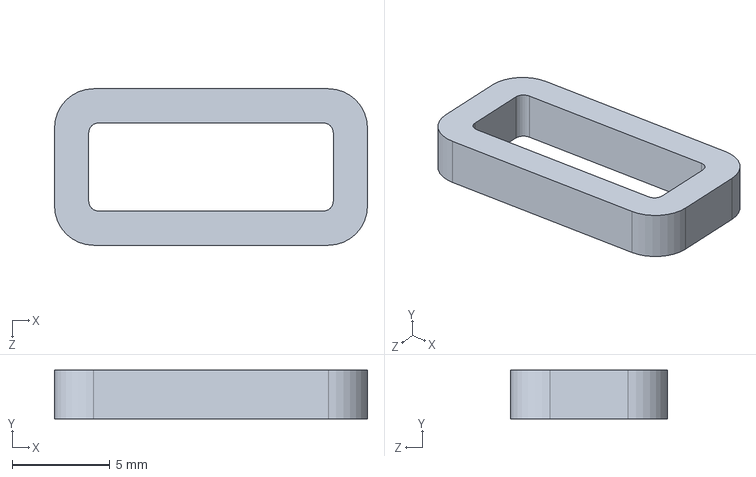
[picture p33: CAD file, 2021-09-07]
ESTRUCTURA DE ACOPLE/Soporte_correas_v2.SLDPRT
16.0 x 2.50 x 8.00 mm

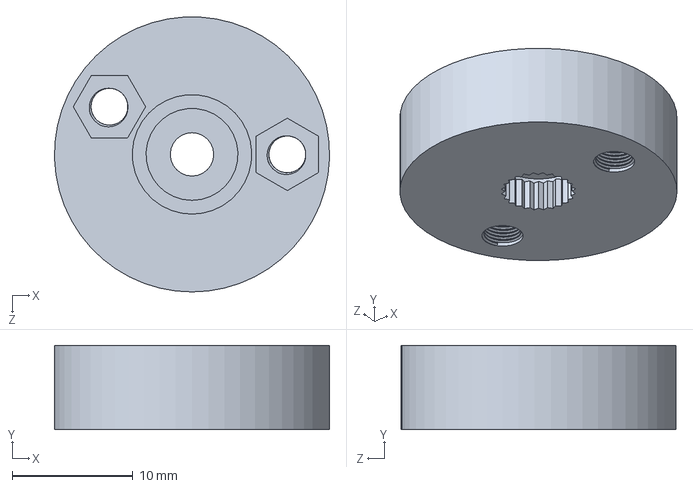
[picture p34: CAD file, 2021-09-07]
ESTRUCTURA DE ACOPLE/Pieza_eje_bien_imprimir_3d_v4.SLDPRT
22.8 x 7.00 x 22.8 mm

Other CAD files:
ESTRUCTURA DE ACOPLE/Ensamblaje2.SLDASM
ESTRUCTURA DE ACOPLE/Servo_motor.SLDASM
ESTRUCTURA DE ACOPLE/Carcasa Servo Hitec HB-755HB.sldprt
ESTRUCTURA DE ACOPLE/pan cross head screw_as_AS-NZS 1427 PC- M1.6 x 5-N.sldprt

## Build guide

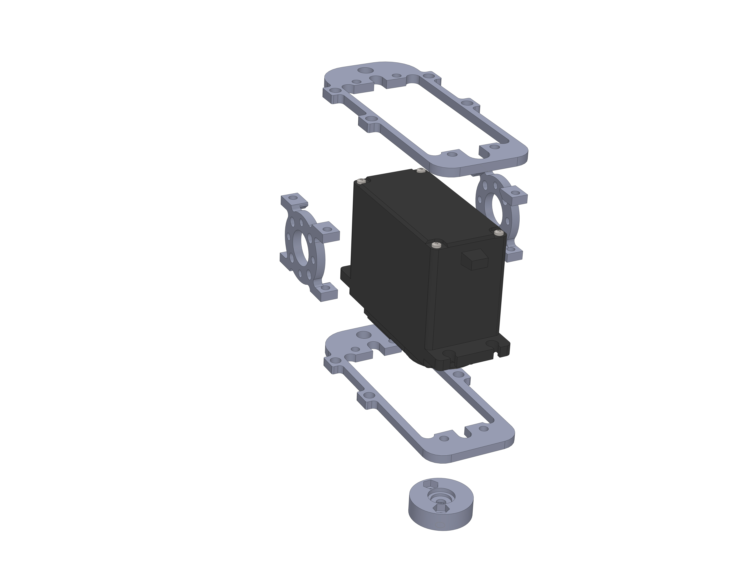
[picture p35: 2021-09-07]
ESTRUCTURA DE ACOPLE/Ensamblaje3_final.JPG

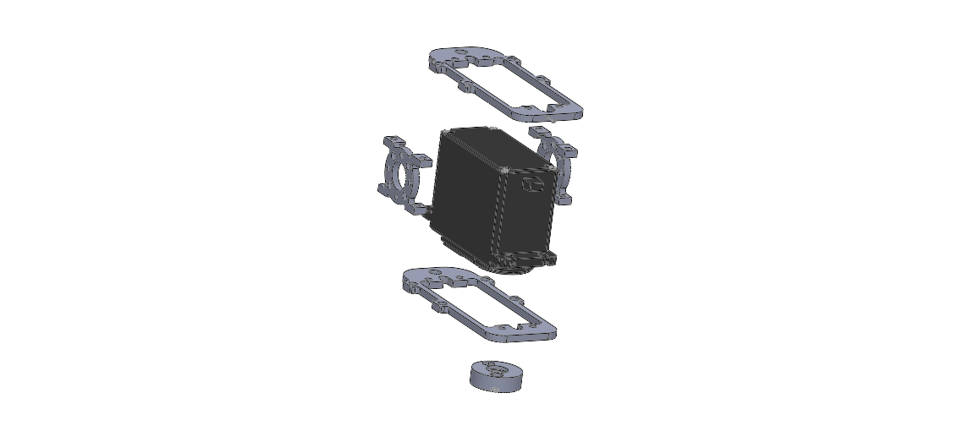
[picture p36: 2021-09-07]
ESTRUCTURA DE ACOPLE/Ensamblaje3.PNG

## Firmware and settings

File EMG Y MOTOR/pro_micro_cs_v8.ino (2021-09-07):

#include <Servo.h>

Servo servo1;  // create servo object to control a servo


int Flexion;
int Extension;
int N_veces;
int Velocidad;
int Delay_flex;
int Delay_ext;
int Pos_inic;

//---------------------------------------
//variables del servomotor
int delay_veloc; //es el delay para variar la velocidad de las repeticiones
int i, j, k;
int pin_servo = 9;
int pulso_min = 625;
//625
int pulso_max = 2450;
//2450


void setup() {
  // put your setup code here, to run once:
  Serial.begin(9600);
  //  delay(100);
  Serial1.begin(9600);
  //delay(100);
  //  Serial.println("Ingrese la configuracion:");
  //  servo1.attach(pin_servo, pulso_min, pulso_max);  // attaches the servo on pin 9 to the servo object
  //  servo1.write(0);                                 // tell servo to go to position in variable 'pos'
  //  delay(20);
    Flexion=0;
    Extension=0;
    N_veces=0;
    Velocidad=0;
    Delay_flex=0;
    Delay_ext=0;
    Pos_inic=0;
}

void loop() {

//int datos2 = Serial1.read();
//Serial.println(datos2);
  //Serial.println("Ingrese la configuracion:");
  if (Serial1.available() > 0) {
    int datos = Serial1.read();
    if (datos == 's') {                                                                                                                                                                                                                                                                                                                                                                                                                                                                                                                                                                                                                                                      
      Flexion = Serial1.parseInt();
      Extension = Serial1.parseInt();
      N_veces = Serial1.parseInt();
      Velocidad = Serial1.parseInt();
      Delay_flex = Serial1.parseInt();
      Delay_ext = Serial1.parseInt();
      Pos_inic = Serial1.parseInt();

      //Con este codigo reviso en la compu si recibi bien los datos
      Serial.println("Su configuracion fue:");
      Serial.println(Flexion);
      Serial.println(Extension);
      Serial.println(N_veces);
      Serial.println(Velocidad);
      Serial.println(Delay_flex);
      Serial.println(Delay_ext);
      Serial.println(Pos_inic);

      //Voy a configurar la velocidad
      // la 3 es la más rápida
      switch (Velocidad) {
        case 1:
          delay_veloc = 35;
          break;
        case 2:
          delay_veloc = 20;
          break;
        case 3:
          delay_veloc = 12;
          break;
      }

      //Ahora voy a hacer la conversion de los parámetros
      // (para que funcione bien el motor):
      Flexion=180-Flexion;
      Extension=180-Extension;
      Delay_flex=Delay_flex*1000;
      Delay_ext=Delay_ext*1000;
      Pos_inic=180-Pos_inic;


      Serial1.print('E');

      k = Pos_inic; //Este valor debe medirse con el goniómetro
      // medir con goniómetro
      if (N_veces > 0) {


        servo1.attach(pin_servo, pulso_min, pulso_max);  // attaches the servo on pin 9 to the servo object
        //j = k;
        for (i = 1; i <= N_veces; i += 1) {

          for (j = k; j <= Flexion; j += 1) {
            servo1.write(j);
            delay(delay_veloc);
          }

          delay(Delay_flex);

          k = j;

          for (j = k; j >= Extension; j -= 1) {
            servo1.write(j);
            delay(delay_veloc);
          }
          delay(Delay_ext);
          k = j;
        }


        //        k = j;
        //        //Con esto regreso a 0 suavemente:
        //        for (j = k; j > 0; j -= 1) {
        //          servo1.write(j);
        //          delay(20);
      }
      Serial.println("La sesión ha terminado");
      Serial1.print('Q');
      servo1.detach(); //Aqui le paro al motor hasta donde se haya quedado en la ultima extension
      Flexion = 0;
      Extension = 0;
      N_veces = 0;
      Velocidad = 0;
      Delay_flex= 0;
      Delay_ext= 0;
      Pos_inic=0;
      i=0;
      j=0;
      k=0;
    }
  }
}

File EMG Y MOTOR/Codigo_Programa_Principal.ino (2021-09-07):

#define sensorPin A0
//Valor de confianza para el low-pass filter
#define alpha 0.20
#include <EEPROM.h>
// twelve servo objects can be created on most boards
double lectura; //Lecturas filtradas que se enviaran por serial
int n_veces; //número de veces de la flexión-extensión 
int i;
int j;
String string = "";
int m = 0;
int pulso_min=500;
int pulso_max=2400;
char palabra[5];
int value = 0;
int Flexion;
int Extension;
int N_veces;
int Velocidad;
int Tiempo_extension;
int Tiempo_flexion;
int P_inicial;
char rutina;
bool rutina_lista=false;


void setup() {
  Serial.begin(9600);
  Serial1.begin(9600);
  Serial2.begin(9600);
}

void loop() {

  
  if((Serial1.available()>0) || (Serial2.available()>0))
  {

    int mensaje = Serial1.read();  //Recibo x el bluetooth
    char mensaje2 = Serial2.read();
    Serial.println(mensaje2);
    //string += mensaje;              //paso a string mensaje 
    //m = string.length();
    // tomo el lenght de string
    
      if (mensaje == 's') {
      Flexion = Serial1.parseInt();
      Extension = Serial1.parseInt();
      N_veces = Serial1.parseInt();
      Velocidad = Serial1.parseInt();
      Tiempo_flexion=Serial1.parseInt();
      Tiempo_extension=Serial1.parseInt();
      P_inicial=Serial1.parseInt();
      rutina_lista=true;
     // digitalWrite(led,HIGH);
      delay(500);
      
//    if (m == 4) {
//    string.toCharArray(palabra, 5);
//    string = "";
//    Serial.println(palabra);
//
//    //TOMA DE LOS VALORES QUE LLEGARON POR EL SERIAL DEL CELULAR
//    
//    Flexion=palabra[0];
//    Extension=palabra[1];
//    N_veces=palabra[3];
//    Velocidad=palabra[2];
//    rutina_lista=true;
//    digitalWrite(led,HIGH);
//    delay(500);
//   
    Serial.println("la rutina esta lista"); 
    }
    else{
     Flexion=0;
     Extension=0;
     N_veces=0;
     Velocidad=0;

  }
      //switch(mensaje){
     //case 'E':
     if ((mensaje=='E') || (mensaje2=='E'))
     {
     start();
     //break; 
     }
     mensaje=0;

     //Si la rutina ya esta lista empiezo la comunicación
  if (rutina_lista==true){ 

      Serial2.println('s');     
      Serial2.print(Flexion);
      Serial.println(Flexion);
      Serial2.print(',');
      Serial2.print(Extension);
      Serial.println(Extension);
      Serial2.print(',');
      Serial2.print(N_veces);
      Serial.println(N_veces);
      Serial2.print(',');
      Serial2.println(Velocidad);
      Serial.println(Velocidad);
      Serial2.print(',');
      Serial2.println(Tiempo_flexion);
      Serial.println(Tiempo_flexion);
      Serial2.print(',');
      Serial2.println(Tiempo_extension);
      Serial.println(Tiempo_extension);
      Serial2.print(P_inicial);
      Serial.println(P_inicial);
      Serial2.print(',');
      rutina_lista=false;
  }
}
}

void start(){
 while(1){
  Serial1.print('s');
  int val=analogRead(sensorPin);
  lectura = (1-alpha)*lectura+alpha*val; //Filtrar estas lecturas
  Serial1.print(floatMap(lectura,0,1023,0,5),2);
  Serial.println(floatMap(lectura,0,1023,0,5),2);
  delay(1);
  
  if((Serial1.available()>0)||(Serial2.available()>0)){
    if ((Serial1.read()=='Q')||(Serial2.read()=='Q')) return;
  }
 }
}
float floatMap(float x, float inMin, float inMax, float outMin, float outMax){
  return (x-inMin)*(outMax-outMin)/(inMax-inMin)+outMin;
}
